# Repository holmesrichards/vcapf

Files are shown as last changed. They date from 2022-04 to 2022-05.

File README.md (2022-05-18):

# Voltage controlled all pass filter

***Note**: At this point the main PCB has been tested and found to be satisfactory, but the first run jacks PCB had errors. They have been corrected [twice] in the design and Gerber files but the [re]corrected board has not been tested. But what are the chances I'd get something so simple wrong ~~twice~~ three times? Shut up, it was a rhetorical question.*

This is an all pass filter (APF) intended to transform LFO wave shapes.

An all pass filter, as the name suggests, passes sine waves of any frequency with no change in amplitude. What does change is the phase angle, the relationship between the zero crossings (or peaks) of the input signal and those of the output. The phase shift depends on the frequency. A single pole APF produces a phase shift varying from 0° at low frequency to -90º at the corner frequency to -180° at high frequency. A two pole APF gives a phase shift from 0° at low frequency to -180º at the corner frequency to -360° at high frequency — the latter half of which is the same as +180° to 0°:

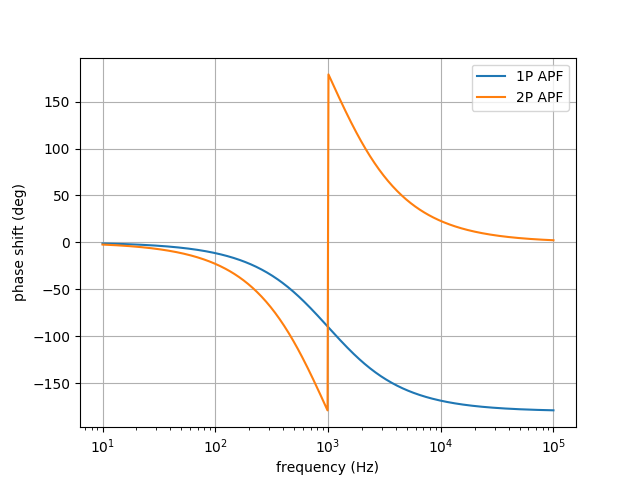
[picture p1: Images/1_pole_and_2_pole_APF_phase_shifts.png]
1 pole and 2 pole APF phase shifts


Putting a non sine periodic wave through an APF changes the wave's shape, since the different harmonics undergo different phase changes; the peak to peak amplitude can change as well, but usually not by a lot. Since the human ear isn't very sensitive to harmonic phases, this doesn't do much of anything interesting to audio waves. But it can produce interesting variants of low frequency CV waveshapes.

This module provides single pole and two pole APF outputs. It has input jacks for an LFO signal and a ±5 V corner frequency control voltage. There are attenuator pots for both inputs, and a knob to set the initial corner frequency.

Simulation results of applying 1- and 2-pole APF with various corner frequencies to triangle, ramp, and square waves are shown below:

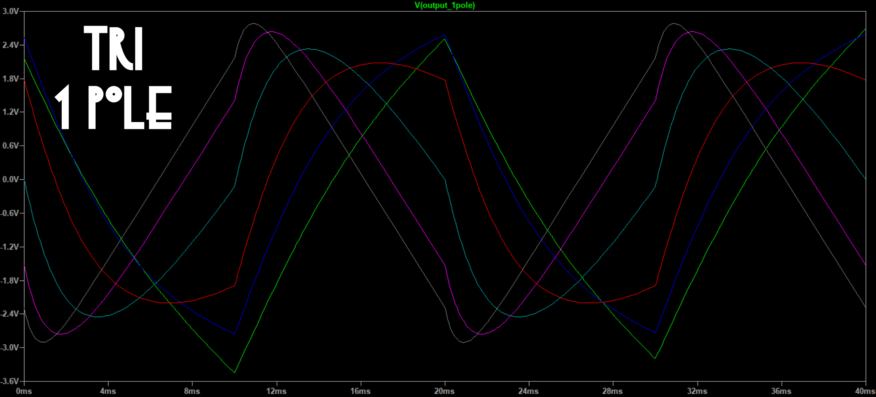
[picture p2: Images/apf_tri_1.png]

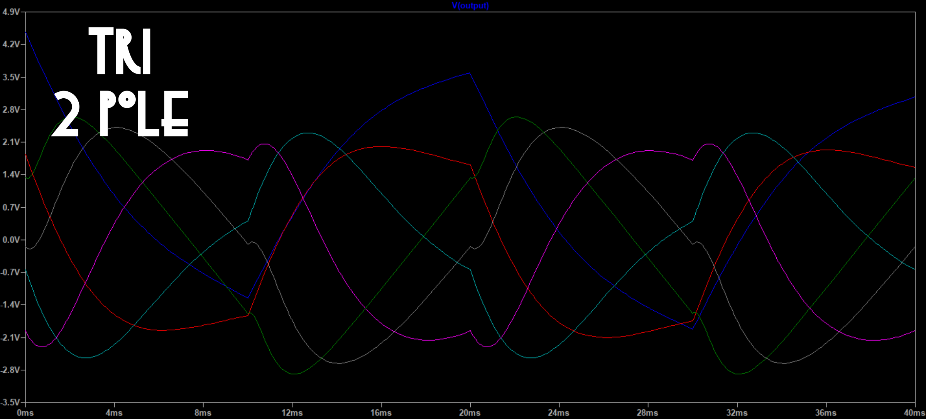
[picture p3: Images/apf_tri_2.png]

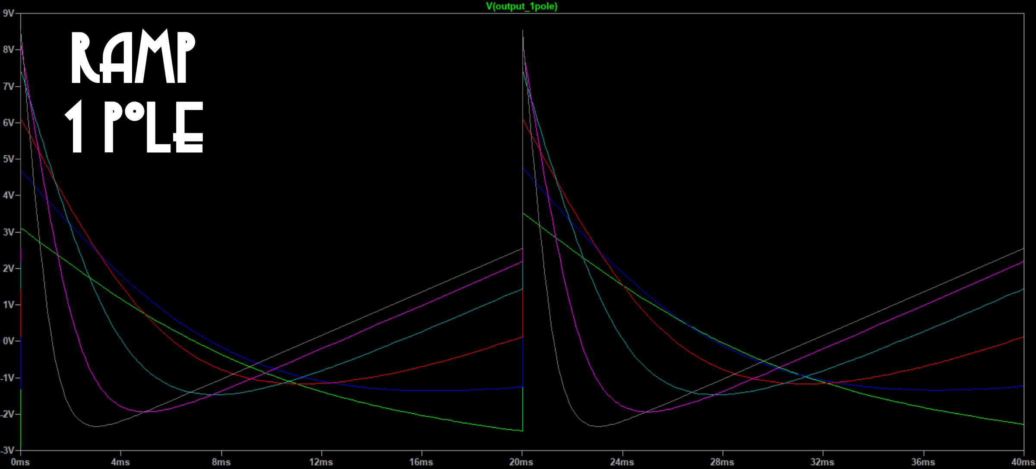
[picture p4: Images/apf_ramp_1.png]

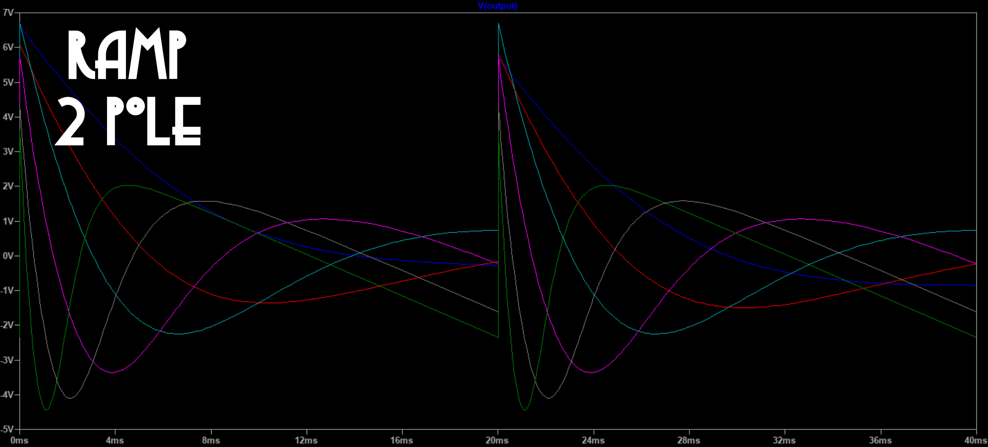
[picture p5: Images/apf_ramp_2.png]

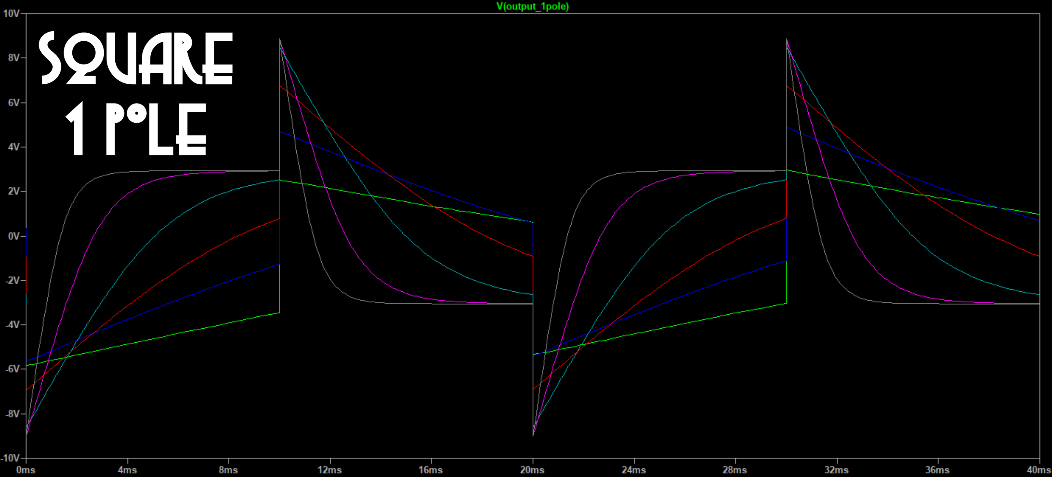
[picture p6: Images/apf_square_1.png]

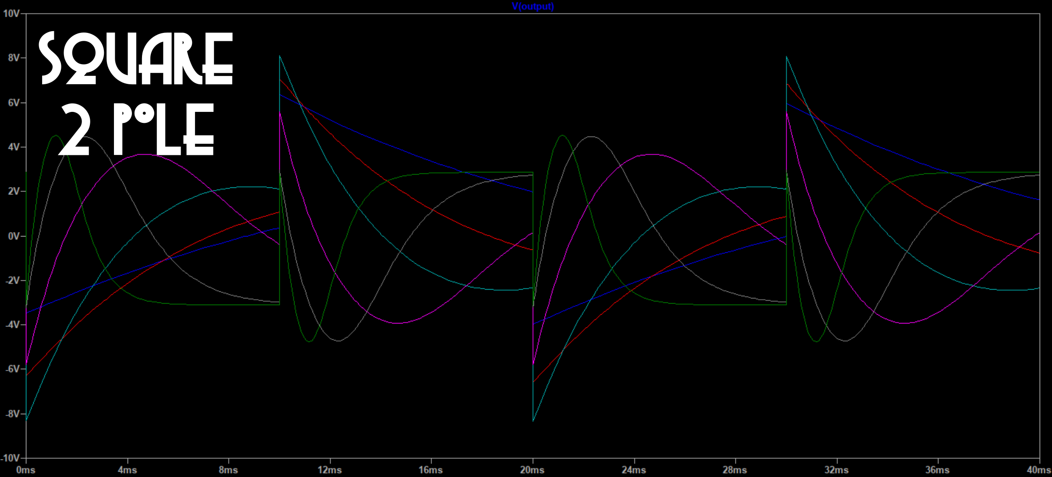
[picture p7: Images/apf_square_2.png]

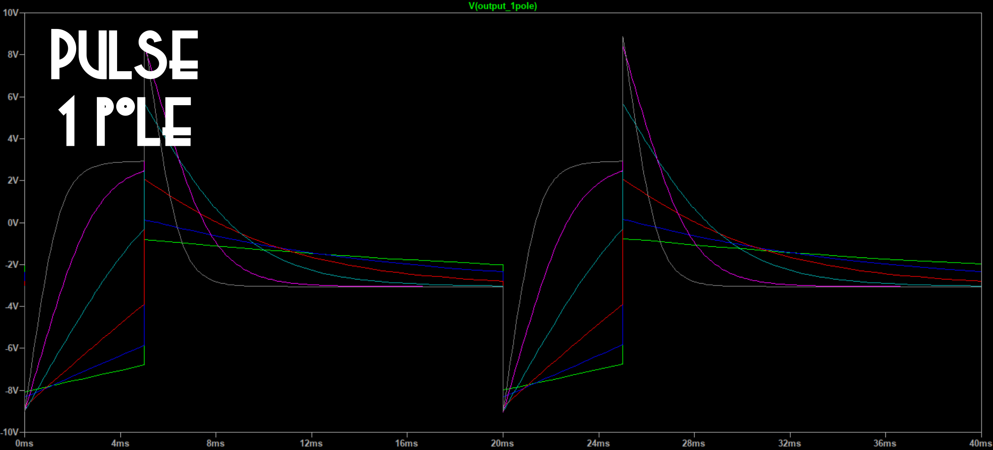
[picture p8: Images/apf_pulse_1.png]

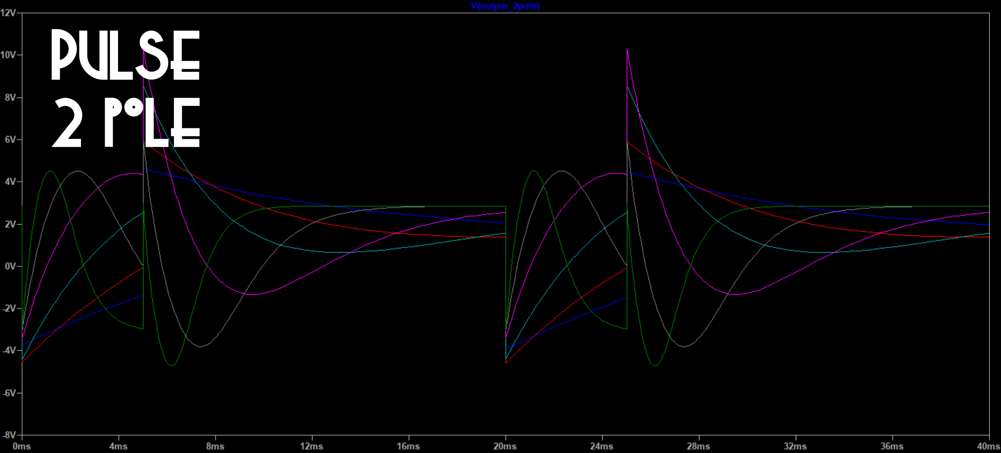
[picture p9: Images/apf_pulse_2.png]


A sin wave will not change shape, but its phase shift may be useful, if you want to vary two patch parameters with out of phase sin waves.

## Circuit description

The circuit is a simple voltage controlled two pole low pass filter (LPF), plus fixed mixing stages for producing APF outputs.

We start with a two pole LPF. This is a very standard design based on the LM13700 OTA datasheet. An exponential converter section transforms the linear control voltage into an exponential control current. Since this module is not intended for audio there is no need for accurate 1 V/oct response, and in fact it is less than 1 V/oct to provide a more useful corner frequency range with ±5 V CV. The filter stages themselves are typical aside from the large (100 nF) capacitors used to optimize the module for low frequency inputs. There is no feedback path to provide resonance, since resonance is not very useful here.

To get APF outputs we use an idea called pole mixing. If the output of a single pole LPF is doubled and subtracted from its input, the result is a single pole APF. To get a two pole APF one can take the input, subtact four times the single pole LPF output, and add four times the two pole LPF output. These mixings are done in op amp mixer stages with fixed resistor inputs. These are inverting stages, which for the single pole APF gives un-inverted (0° phase shift) output at low frequency. For the two pole APF we get inverted (180° phase shift) output at low frequency, so for consistency this signal goes through an additional inverting stage to obtain an un-inverted signal at low frequency at the output jack.

## LM13700

I designed the PCB to use the DIP version of the LM13700. This chip is out of production and getting harder to come by, though the SOIC version is available. I found these SOIC to DIP breakouts

* Chip-Quik PA0005 [https://www.digikey.com/en/products/detail/chip-quik-inc/PA0005/5014715](https://www.digikey.com/en/products/detail/chip-quik-inc/PA0005/5014715)
* Chip-Quik PA0005C [https://www.digikey.com/en/products/detail/chip-quik-inc/PA0005C/12352178](https://www.digikey.com/en/products/detail/chip-quik-inc/PA0005C/12352178)

one or the other of which probably could be used to assemble this PCB with a SOIC LM13700 — the second of those is narrower but costs more, and I think the first would work. (But I have a stash of DIP LM13700, so I haven't tried this.)

## Current draw
? mA +12 V, ? mA -12 V

## Photos

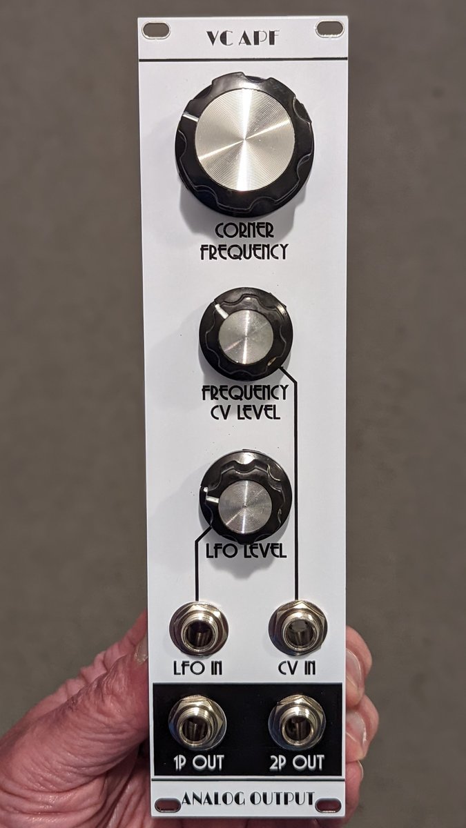
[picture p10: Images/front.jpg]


## Documentation

* [Schematic](Docs/vcapf.pdf)
* PCB layout: [front](Docs/vcapf_layout_front.pdf), [back](Docs/vcapf_layout_back.pdf)
* [BOM](Docs/vcapf_bom.md)
* [Build notes](Docs/build.md)
* [Blog post](https://analogoutputblog.wordpress.com/2022/05/07/voltage-controlled-all-pass-filter/)

## GitHub repository

* [https://github.com/holmesrichards/vcapf](https://github.com/holmesrichards/vcapf)

## Submodules

This repo uses submodules aoKicad and Kosmo_panel, which provide needed libaries for KiCad. To clone:

```
git clone git@github.com:holmesrichards/vcapf.git
git submodule init
git submodule update
```

Alternatively do

```
git clone --recurse-submodules git@github.com:holmesrichards/vcapf.git
```

Or if you download the repository as a zip file, you must also click on the "aoKicad" and "Kosmo\_panel" links on the GitHub page (they'll have "@ something" after them) and download them as separate zip files which you can unzip into this repo's aoKicad and Kosmo\_panel directories.

If desired, copy the files from aoKicad and Kosmo\_panel to wherever you prefer (your KiCad user library directory, for instance, if you have one). Then in KiCad, go into Edit Symbols and add symbol libraries 

```
aoKicad/ao_symbols
Kosmo_panel/Kosmo
```
and go into Edit Footprints and add footprint libraries 
```
aoKicad/ao_tht
Kosmo_panel/Kosmo_panel.
```

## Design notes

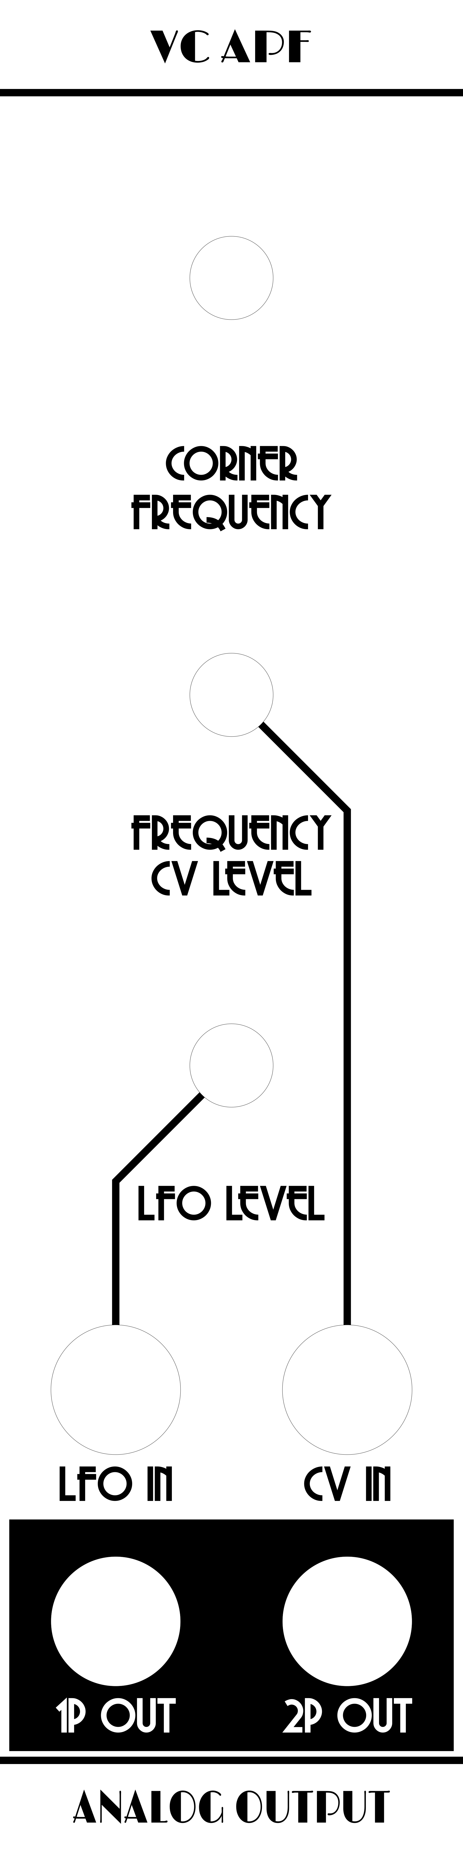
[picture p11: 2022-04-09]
Images/vcapf_panel_art.png

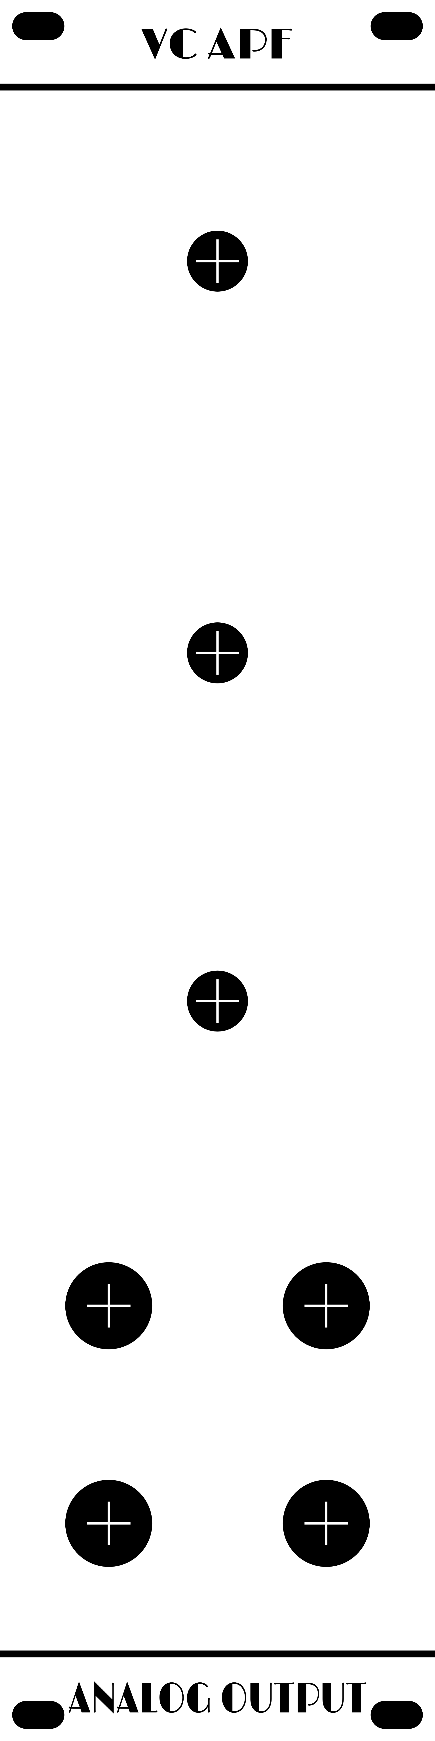
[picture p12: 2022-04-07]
Images/vcapf_panel_holes.png

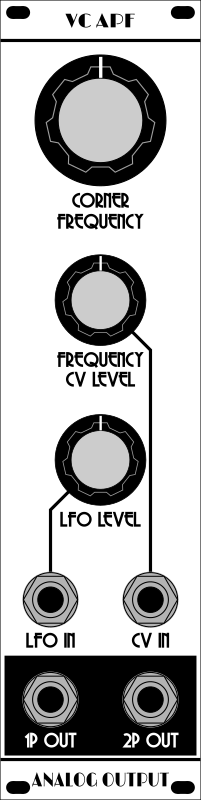
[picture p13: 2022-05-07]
Images/vcapf_panel.png

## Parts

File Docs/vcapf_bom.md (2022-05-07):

# vcapf.kicad_sch BOM

Sat 07 May 2022 05:50:25 PM EDT

Generated from schematic by Eeschema 6.0.5-a6ca702e91~116~ubuntu20.04.1

**Component Count:** 57

| Refs | Qty | Component | Description | Vendor | SKU |
| ----- | --- | ---- | --- | ---- | ---- |
| C1, C2 | 2 | 10uF | Electrolytic capacitor, 2.5 mm pitch | Tayda | A-4349 |
| C3, C4, C7, C8, C9, C10 | 6 | 100nF | Ceramic capacitor, 2.5 mm pitch | Tayda | A-553 |
| C5, C11 | 2 | 100nF | Polyester capacitor | Tayda | A-564 |
| C6 | 1 | 4.7nF | Ceramic capacitor, 2.5 mm pitch | Tayda |  |
| D1, D2 | 2 | 1N5817 | Schottky Barrier Rectifier Diode, DO-41 | Tayda | A-159 |
| D3 | 1 | 1N4148 | Standard switching diode, DO-35 | Tayda | A-157 |
| J1 | 1 | Synth_power_2x5 | Pin header 2.54 mm 2x5 | Tayda | A-2939 |
| J2, J3, J6, J7 | 4 | AudioJack2 | 1/4" audio jack, vertical | Tayda | A-1121 |
| J4 | 1 | Conn_01x05 | 5 pin socket, 2.5 mm pitch | Tayda | A-196 (cut) |
| J5 | 1 | Conn_01x05 | 5 pin header, 2.5 mm pitch | Tayda | A-197 (cut) |
| Q1, Q2 | 2 | 2N3906 matched | -0.2A Ic, -40V Vce, Small Signal PNP Transistor, TO-92 | Tayda | A-117 |
| R1, R2, R5, R7, R10, R15, R17 | 7 | 100k | 1/4 watt resistor, metal film | Tayda |  |
| R3, R4 | 2 | 1k | 1/4 watt resistor, metal film | Tayda |  |
| R6, R12 | 2 | 470k | 1/4 watt resistor, metal film | Tayda |  |
| R8 | 1 | 2.7k | 1/4 watt resistor, metal film | Tayda |  |
| R9, R11, R16, R18 | 4 | 620R | 1/4 watt resistor, metal film | Tayda |  |
| R13, R19 | 2 | 6.8k | 1/4 watt resistor, metal film | Tayda |  |
| R14 | 1 | 4.7k | 1/4 watt resistor, metal film | Tayda |  |
| R20, R22, R26, R27 | 4 | 30k | 1/4 watt resistor, metal film | Tayda |  |
| R21 | 1 | 15k | 1/4 watt resistor, metal film | Tayda |  |
| R23, R24 | 2 | 7.5k | 1/4 watt resistor, metal film | Tayda |  |
| R25, R28 | 2 | 10k | 1/4 watt resistor, metal film | Tayda |  |
| RV1, RV2, RV3 | 3 | 100k | Linear potentiometer, 16 mm, PCB mount, vertical | Tayda | A-1628 |
| U1 | 1 | LM13700 | Dual OTA, DIP-16* | Tayda | A-900 |
| U2 | 1 | TL074 | Quad operational amplifier, DIP-14 | Tayda | A-1138 |
| U3 | 1 | TL072 | Dual operational amplifier, DIP-8 | Tayda | A-037 |
| | 1 | | 8 pin DIP socket | Tayda | A-001 |
| | 1 | | 14 pin DIP socket | Tayda | A-004 |
| | 1 | | 16 pin DIP socket | Tayda | A-003 |
| | 3 | | knobs | | |
    
\* See [README](../README.md) regarding LM13700 availability and alternative

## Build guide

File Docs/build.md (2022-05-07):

# VCAPF build notes

It's a standard build. No errors to note. Nothing weird to explain. Just build it.

Oh, the two transistors in principle should be [matched](https://web.archive.org/web/20151002134800if_/http://home.comcast.net/~ijfritz/MiscProj/transmat001.pdf). In practice you'd probably never know the difference. I put the first two 2N3906 I could find in the matching circuit, measured a voltage difference of 0.4 mV, and figured there was no point in looking at a third transistor.

There are holes provided for attaching the two boards together with spacers, but since both boards are attached to the front panel, this isn't really necessary.

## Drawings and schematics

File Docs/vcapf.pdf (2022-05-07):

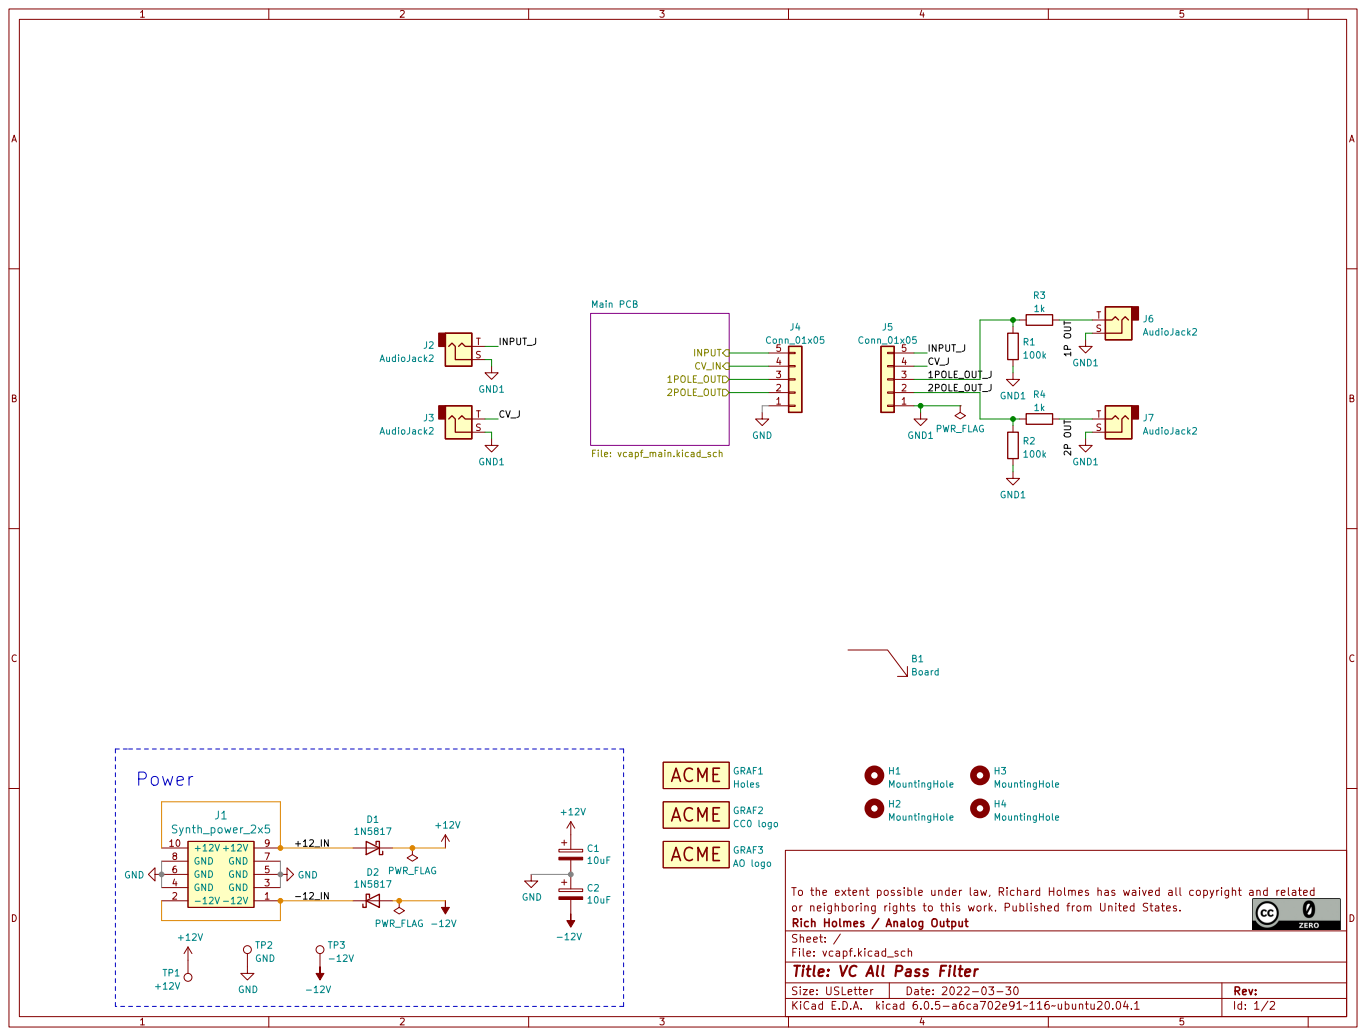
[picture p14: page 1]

To the extent possible under law, Richard Holmes has waived all copyright and related
or neighboring rights to this work. Published from United States.
File: vcapf.kicad_sch Sheet: / Rich Holmes / Analog Output

Id: 1/2 Title: VC All Pass Filter

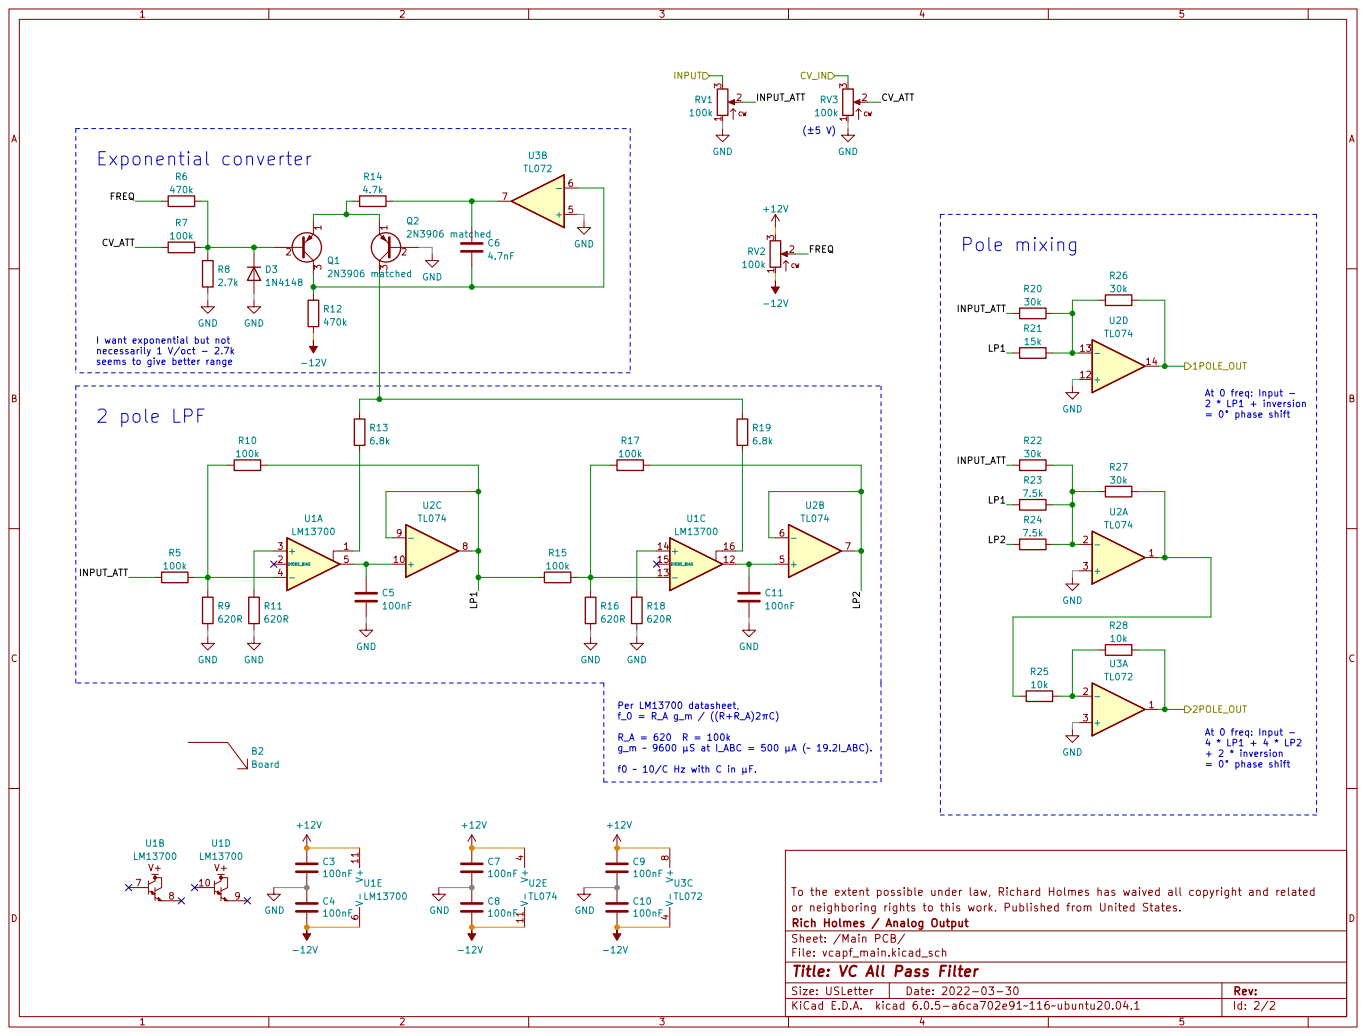
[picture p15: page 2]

INPUT_ATT Per LM13700 datasheet, þÿf_0 = R_A g_m / ((R+R_A)2ÀC) R_A = 620 R = 100k þÿg_m ~ 9600 µS at I_ABC = 500 µA (~ 19.2I_ABC).

I want exponential but not
necessarily 1 V/oct - 2.7k
seems to give better range

At 0 freq: Input - 2 * LP1 + inversion

To the extent possible under law, Richard Holmes has waived all copyright and related +

At 0 freq: Input - 4 * LP1 + 4 * LP2 + 2 * inversion

or neighboring rights to this work. Published from United States.
File: vcapf_main.kicad_sch Sheet: /Main PCB/ Rich Holmes / Analog Output

Id: 2/2 Title: VC All Pass Filter

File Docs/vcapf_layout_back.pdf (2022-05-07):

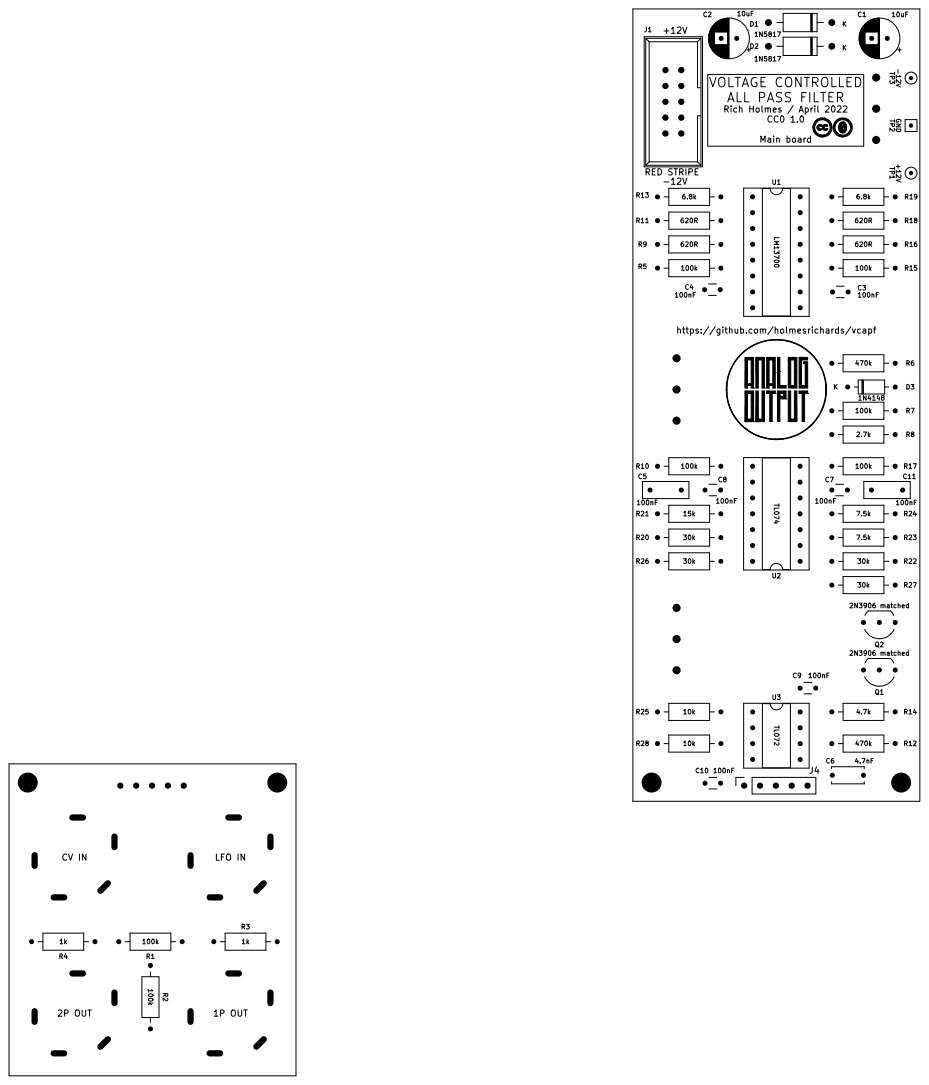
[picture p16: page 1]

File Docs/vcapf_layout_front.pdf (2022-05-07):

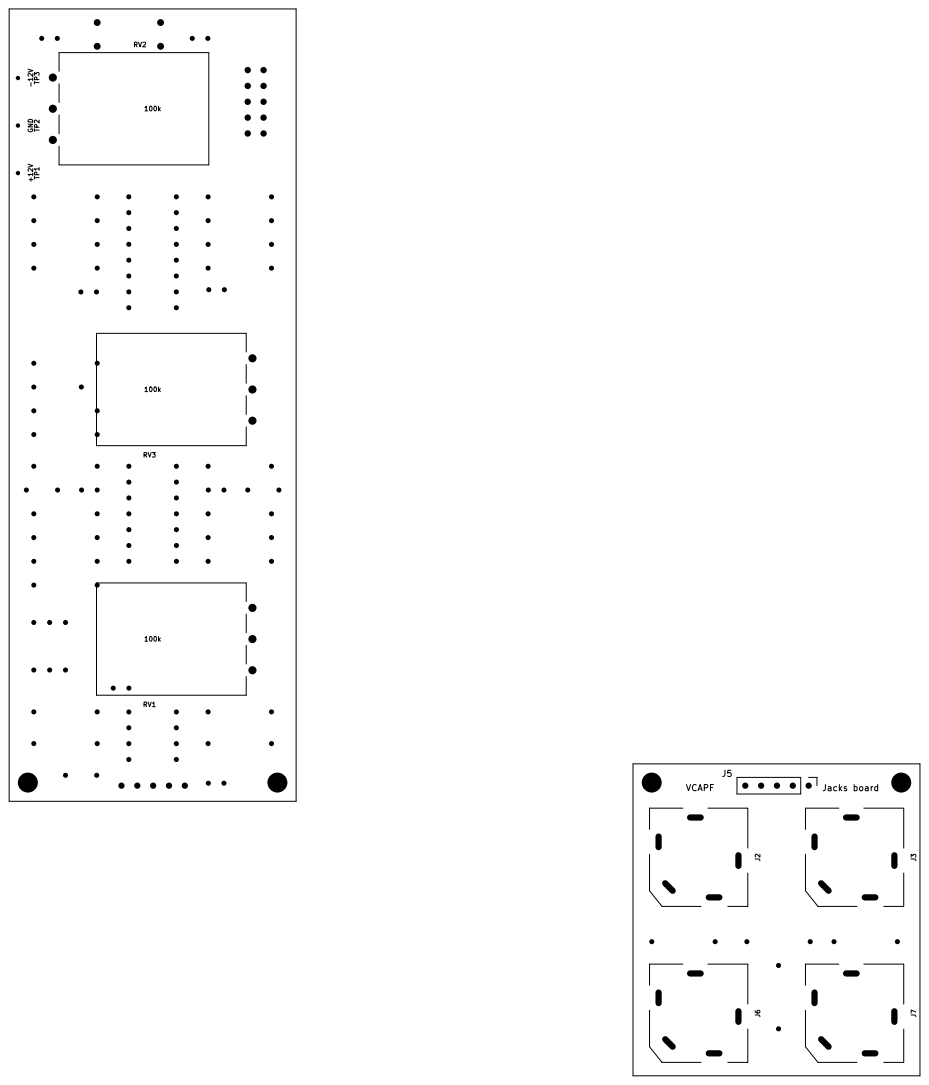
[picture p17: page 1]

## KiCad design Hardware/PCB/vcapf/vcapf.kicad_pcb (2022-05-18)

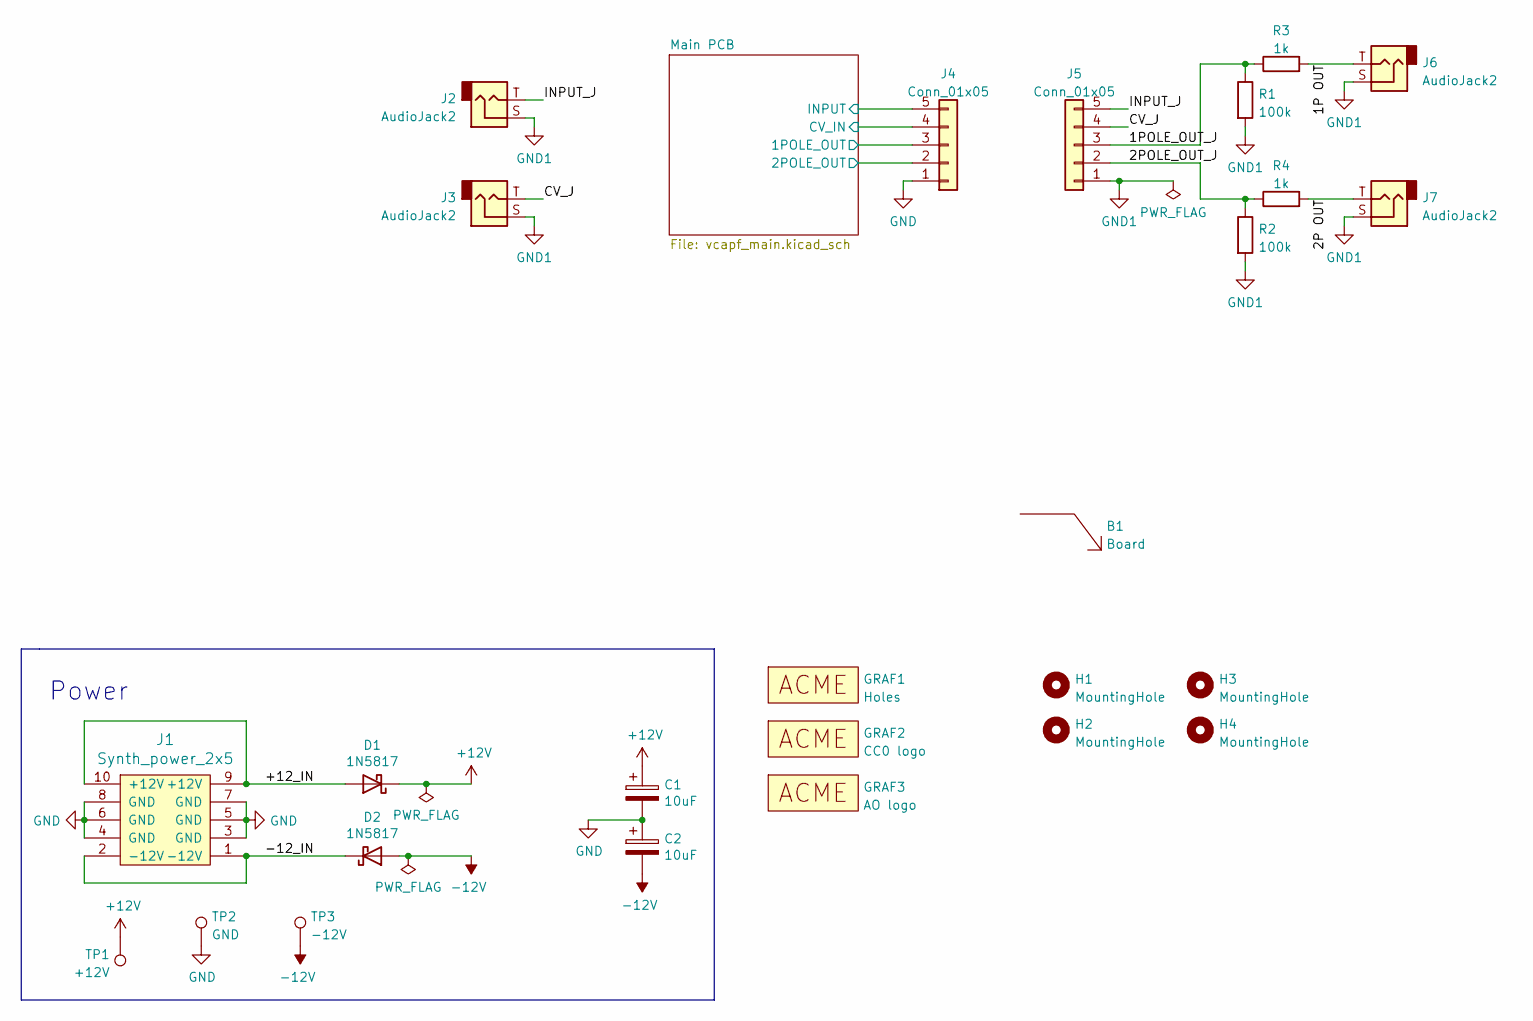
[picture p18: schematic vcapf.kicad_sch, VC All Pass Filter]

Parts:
B1: Board; Board_Marker
C1, C2: 10uF; CP_Radial_D6.3mm_P2.50mm
D1, D2: 1N5817; D_DO-41_SOD81_P10.16mm_Horizontal
GRAF1: Holes; vcapf_panel_holes
GRAF2: CC0 logo; CC0_logo
GRAF3: AO logo; analogoutput
H1, H2, H3, H4: MountingHole; MountingHole_3.2mm_M3
J1: Synth_power_2x5; Power_Header
J2, J3, J6, J7: AudioJack2; Jack_6.35mm_PJ_629HAN_slots
J4: Conn_01x05; PinSocket_1x05_P2.54mm_Vertical
J5: Conn_01x05; PinHeader_1x05_P2.54mm_Vertical
R1, R2: 100k; R_Axial_DIN0207_L6.3mm_D2.5mm_P10.16mm_Horizontal
R3, R4: 1k; R_Axial_DIN0207_L6.3mm_D2.5mm_P10.16mm_Horizontal
TP1: +12V; TestPoint_THTPad_D1.5mm_Drill0.7mm
TP2: GND; TestPoint_THTPad_1.5x1.5mm_Drill0.7mm
TP3: -12V; TestPoint_THTPad_D1.5mm_Drill0.7mm

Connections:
+12V: C1.1, D1.1 (K), TP1.1; also elsewhere on the board
-12V: C2.2, D2.2 (A), TP3.1; also elsewhere on the board
/1P OUT: J6.T, R3.2
/1POLE_OUT_J: J5.3, R1.1, R3.1
/2P OUT: J7.T, R4.2
/2POLE_OUT_J: J5.2, R2.1, R4.1
/+12_IN: D1.2 (A), J1.9 (+12V), J1.10 (+12V)
/-12_IN: D2.1 (K), J1.1 (-12V), J1.2 (-12V)
/CV_J: J3.T, J5.4
/INPUT_J: J2.T, J5.5
/Main PCB/1POLE_OUT: J4.3; also elsewhere on the board
/Main PCB/2POLE_OUT: J4.2; also elsewhere on the board
/Main PCB/CV_IN: J4.4; also elsewhere on the board
/Main PCB/INPUT: J4.5; also elsewhere on the board
GND: C1.2, C2.1, J1.3 (GND), J1.4 (GND), J1.5 (GND), J1.6 (GND), J1.7 (GND), J1.8 (GND), J4.1, TP2.1; also elsewhere on the board
GND1: J2.S, J3.S, J5.1, J6.S, J7.S, R1.2, R2.2

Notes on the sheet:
Power

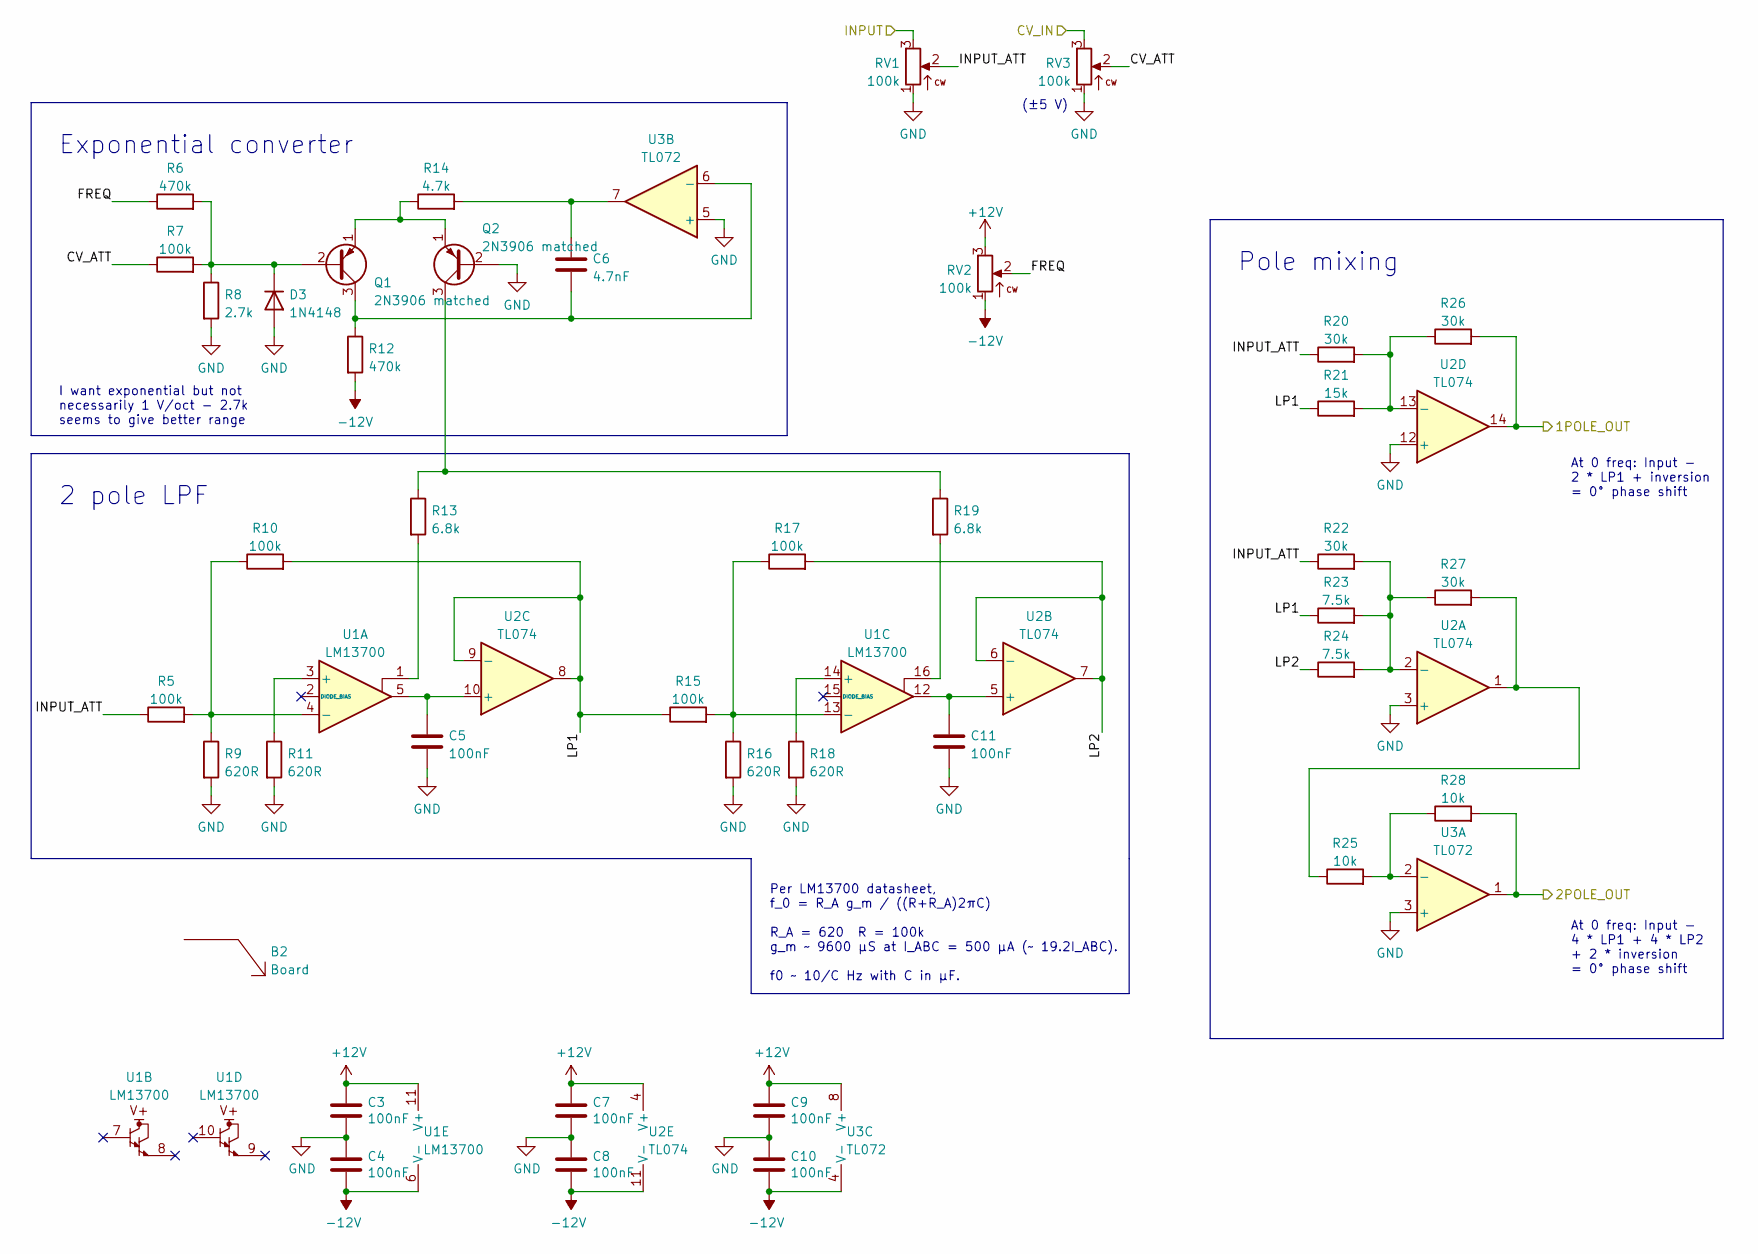
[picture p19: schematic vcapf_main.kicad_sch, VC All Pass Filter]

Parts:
B2: Board; Board_Marker
C3, C4, C7, C8, C9, C10: 100nF; C_Disc_D3.0mm_W1.6mm_P2.50mm
C5, C11: 100nF; C_Rect_L7.2mm_W2.5mm_P5.00mm_FKS2_FKP2_MKS2_MKP2
C6: 4.7nF; C_Disc_D5.0mm_W2.5mm_P5.00mm
D3: 1N4148; D_DO-35_SOD27_P7.62mm_Horizontal
Q1, Q2: 2N3906 matched; TO-92_Inline_Wide
R5, R7, R10, R15, R17: 100k; R_Axial_DIN0207_L6.3mm_D2.5mm_P10.16mm_Horizontal
R6, R12: 470k; R_Axial_DIN0207_L6.3mm_D2.5mm_P10.16mm_Horizontal
R8: 2.7k; R_Axial_DIN0207_L6.3mm_D2.5mm_P10.16mm_Horizontal
R9, R11, R16, R18: 620R; R_Axial_DIN0207_L6.3mm_D2.5mm_P10.16mm_Horizontal
R13, R19: 6.8k; R_Axial_DIN0207_L6.3mm_D2.5mm_P10.16mm_Horizontal
R14: 4.7k; R_Axial_DIN0207_L6.3mm_D2.5mm_P10.16mm_Horizontal
R20, R22, R26, R27: 30k; R_Axial_DIN0207_L6.3mm_D2.5mm_P10.16mm_Horizontal
R21: 15k; R_Axial_DIN0207_L6.3mm_D2.5mm_P10.16mm_Horizontal
R23, R24: 7.5k; R_Axial_DIN0207_L6.3mm_D2.5mm_P10.16mm_Horizontal
R25, R28: 10k; R_Axial_DIN0207_L6.3mm_D2.5mm_P10.16mm_Horizontal
RV1, RV2, RV3: 100k; Potentiometer_Alpha_16mm_Single_Vertical
U1: LM13700; DIP-16_W7.62mm_Socket_LongPads
U2: TL074; DIP-14_W7.62mm_Socket_LongPads
U3: TL072; DIP-8_W7.62mm_Socket_LongPads

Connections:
+12V: C3.1, C7.1, C9.1, RV2.3, U1.11 (V+), U2.4 (V+), U3.8 (V+); also elsewhere on the board
-12V: C4.2, C8.2, C10.2, R12.2, RV2.1, U1.6 (V-), U2.11 (V-), U3.4 (V-); also elsewhere on the board
/Main PCB/1POLE_OUT: R26.2, U2.14; also elsewhere on the board
/Main PCB/2POLE_OUT: R28.2, U3.1; also elsewhere on the board
/Main PCB/CV_ATT: R7.1, RV3.2
/Main PCB/CV_IN: RV3.3; also elsewhere on the board
/Main PCB/FREQ: R6.1, RV2.2
/Main PCB/INPUT: RV1.3; also elsewhere on the board
/Main PCB/INPUT_ATT: R5.1, R20.1, R22.1, RV1.2
/Main PCB/LP1: R10.2, R15.1, R21.1, R23.1, U2.8, U2.9 (-)
/Main PCB/LP2: R17.2, R24.1, U2.6 (-), U2.7
GND: C3.2, C4.1, C5.2, C7.2, C8.1, C9.2, C10.1, C11.2, D3.2 (A), Q2.2 (B), R8.2, R9.2, R11.2, R16.2, R18.2, RV1.1, RV3.1, U2.3 (+), U2.12 (+), U3.3 (+), U3.5 (+); also elsewhere on the board
unnamed: C5.1, U1.5, U2.10 (+)
unnamed: C6.1, R14.2, U3.7
unnamed: C6.2, Q1.3 (C), R12.1, U3.6 (-)
unnamed: C11.1, U1.12, U2.5 (+)
unnamed: D3.1 (K), Q1.2 (B), R6.2, R7.2, R8.1
unnamed: Q1.1 (E), Q2.1 (E), R14.1
unnamed: Q2.3 (C), R13.1, R19.1
unnamed: R5.2, R9.1, R10.1, U1.4 (-)
unnamed: R11.1, U1.3 (+)
unnamed: R13.2, U1.1
unnamed: R15.2, R16.1, R17.1, U1.13 (-)
unnamed: R18.1, U1.14 (+)
unnamed: R19.2, U1.16
unnamed: R20.2, R21.2, R26.1, U2.13 (-)
unnamed: R22.2, R23.2, R24.2, R27.1, U2.2 (-)
unnamed: R25.1, R27.2, U2.1
unnamed: R25.2, R28.1, U3.2 (-)

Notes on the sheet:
(±5 V)
Per LM13700 datasheet, f_0 = R_A g_m / ((R+R_A)2πC) R_A = 620 R = 100k g_m ~ 9600 µS at I_ABC = 500 µA (~ 19.2I_ABC). f0 ~ 10/C Hz with C in µF.
2 pole LPF
At 0 freq: Input - 4 * LP1 + 4 * LP2 + 2 * inversion = 0° phase shift
At 0 freq: Input - 2 * LP1 + inversion = 0° phase shift
I want exponential but not necessarily 1 V/oct - 2.7k seems to give better range
Exponential converter
Pole mixing

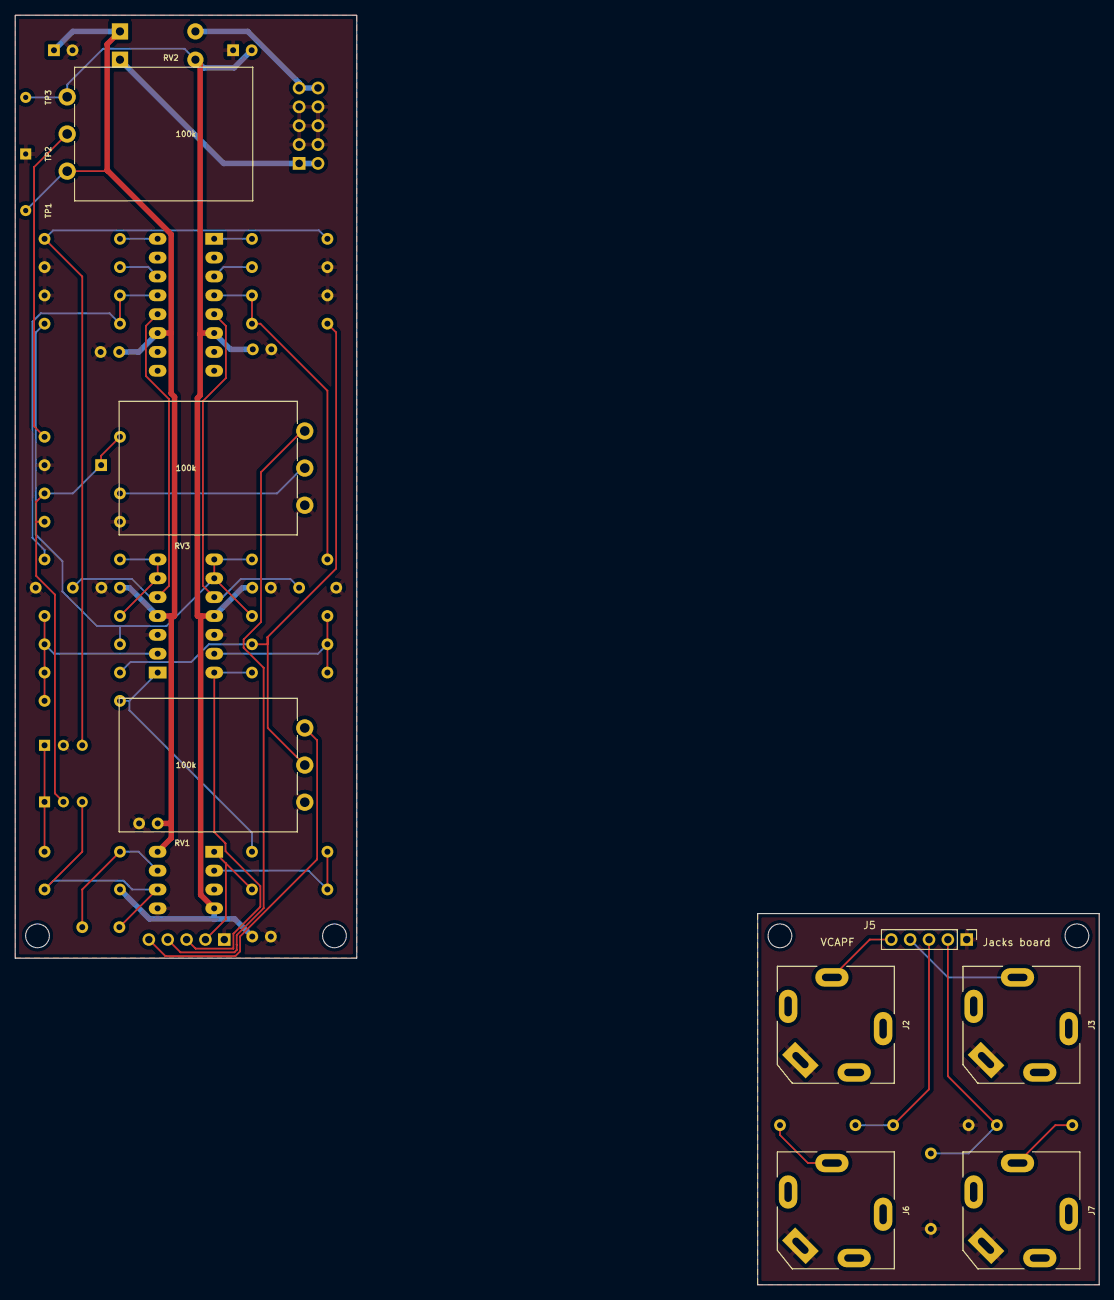
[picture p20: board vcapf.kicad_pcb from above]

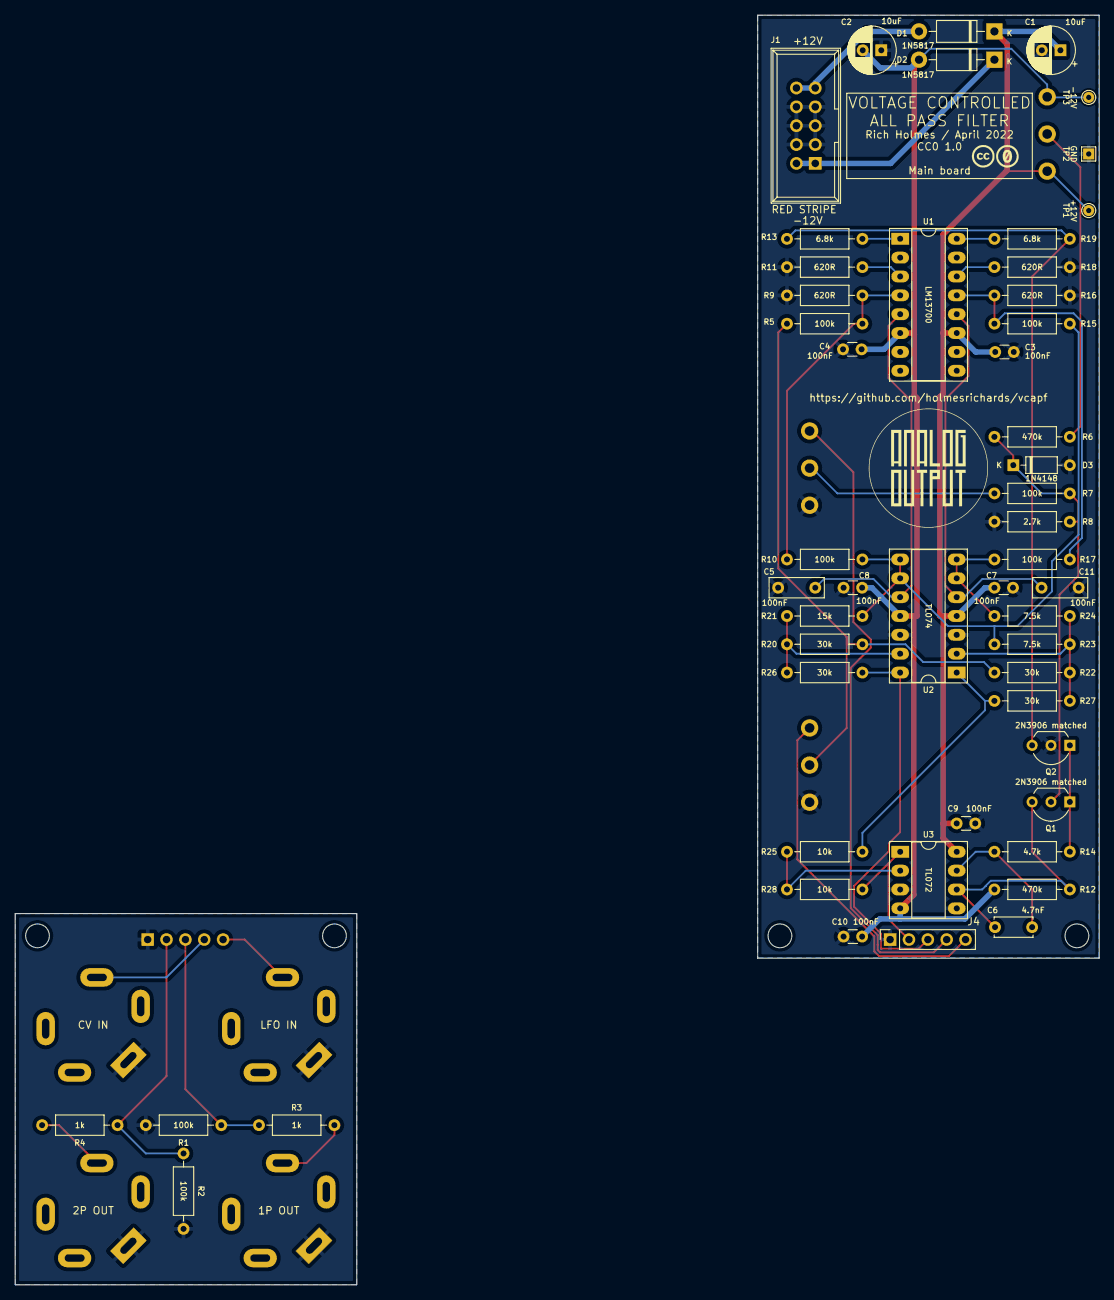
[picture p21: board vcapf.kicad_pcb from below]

Board: 2 copper layers, 46.0 x 127.0 mm, 69 parts (54 on the bottom side), 38 nets.

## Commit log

2022-04-04 Initial version
    [vcapf.kicad_pcb, vcapf.kicad_sch]
2022-04-07 Post breadboard tweaks; layout
    [vcapf.kicad_pcb, vcapf.kicad_sch, vcapf_main.kicad_sch]
2022-04-08 Layout corrections, pot position and main board length
    [vcapf.kicad_pcb]
2022-04-09 Net labels, panel
    [vcapf.kicad_pcb, vcapf.kicad_sch, vcapf_panel.kicad_pcb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]
2022-04-10 Match transistors
    [vcapf.kicad_sch, vcapf_main.kicad_sch]
2022-04-17 BOM, README revision
2022-05-07 Pre fab tweaks, unreverse jacks, Gerbers
    [vcapf.kicad_pcb, vcapf.kicad_sch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]
2022-05-07 Post fab updates
    [vcapf.kicad_sch, vcapf_main.kicad_sch]
2022-05-18 Fill jacks board
    [vcapf.kicad_pcb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]
